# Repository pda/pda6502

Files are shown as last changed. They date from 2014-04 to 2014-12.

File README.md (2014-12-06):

pda6502
=======

pda6502 is a home-built computer powered by an 8-bit [6502][6502] CPU
([WDC 65C02][65C02]), varitions of which powered the venerable Commodore 64,
Apple II, Vic 20, Nintendo and lots more.

[74HC-series][7400] logic chips map the 64K address space to 32K RAM, 8K ROM, a
[6522 VIA I/O controller][6522], and room for expansion.

The first output device (beyond flashing LEDs) is a [128x32 pixel OLED][oled],
connected to one of the VIA 6522 parallel ports, with bit-banged serial comms.

It's currently exclusively running the 6502 assembly code which I've written in
the `src/` directory of this project. As of April 2014, it can bit-bang SPI on
the VIA parallel ports to drive the OLED display, rendering text using the old
Commodore 64 font data.

The code is assembled with [ca65][ca65], part of the [cc65][cc65] 6502
development package.

Notes
-----

ILI9340 SPI performance; filling 200x200 square.
baseline: 4.5 seconds.

Emulator
--------

I've also written [go6502][go6502], an emulator for this system.

go6502 features a stepping debugger with breakpoints on instruction type,
register values and memory location. This makes it far easier to get code
working correctly before writing it to an actual EEPROM.

Address layout
--------------

Considerations:

* 6502 has 16-bit address bus; can address 64K memory.
* Zero-page (0x0000..0x00FF) must be RAM, used as external registers.
* Stack (0x0100..0x00FF) must be RAM.
* PC (program counter) is initialized from 0xFFFC, so must be ROM.
* 6522 VIA (I/O) has 4-bit RS (register select), needs 16 bytes mapped.
* AT28C64 EEPROMs are 8kb. I have some.
* Nice to have:
  * Fancy bank-switching (e.g. ROMs overlaying RAM, C64-style).
  * Different mapping for read vs. write, e.g. read ROM, write RAM.

74HC521/74HC688 can route a specific page (256 bytes, upper 8 bits of address)
to a destination. See http://wilsonminesco.com/6502primer/addr_decoding.html

So using the highest three pins of the address bus, the memory space
can be divided down to 8K blocks.

A simple RAM+ROM+IO scheme:
Allows for future extensions e.g. upper 32K RAM, with ROMs and I/O overlaid.

* 0x0000..0x7FFF: 32K RAM, uninterrupted. Contains zero-page and stack.
* 0x8000..0xBFFF: (reserved)
* 0xC000..0xCFFF: 4K I/O (initially only 16 bytes used by 6522 VIA)
* 0xD000..0xDFFF: (reserved)
* 0xE000..0xFFFF: 8K ROM ("kernal" [sic])

Address table for upper 3 bits of address bus:

NOTE: A15 can directly control RAM's CE/OE.
      This means a 74HC138 decoder can run on A12..14
      (With A15 as the '138 active-high enable input)

Address bus 4 KB chunks:

```
     High   Dec  Dec
Seg  Bits    In  Out  Base    Function
------------------------------------------------
  0  0000             0x0000  RAM
  1  0001             0x1000  RAM
  2  0010             0x2000  RAM
  3  0011             0x3000  RAM
  4  0100             0x4000  RAM
  5  0101             0x5000  RAM
  6  0110             0x6000  RAM
  7  0111             0x7000  RAM
  8  1000   000    0  0x8000
  9  1001   100    4  0x9000  IO (VIA) (should be at 0xC000)
  A  1010   010    2  0xA000
  B  1011   110    6  0xB000  ROM (KERNAL) (should be at 0xE000)
  C  1100   001    1  0xC000
  D  1101   101    5  0xD000
  E  1110   011    3  0xE000
  F  1111   111    7  0xF000  ROM (KERNAL)
```

* 74HC138 (3-to-8 decoder)
    * G1 (active-high enable) driven by A15 (only active 0x8000 and above)
    * G2 (active-low enable) permanently LOW/enabled.
    * Inputs A, B, C driven by A12, A13, A14.
    * Output Y4 enables VIA.
    * Output Y6 & Y7 drive KERNAL ROM via AND gate.
* 74HC08 (Quad 2-input AND gates)
    * Input A1, B1 from 74HC138 Y6, Y7, output Y1 to KERNAL ROM CE/OE.
    * Input A2, B2 from phase2, A15, output Y2 to RAM CS/OE.
    * Three spare AND gates.
* 74HC00 (Quad 2-input NAND gates)
    * Input A1, B1 from A15 (as inverter), output Y1 to A2.
    * Input A2, B2 from Y1, phase2 clock, output Y2 to RAM CS/OE.
* VIA 6522
    * CS1 permanently HIGH/active.
    * CS2B to 74HC138 Y4 (LOW/active for `0b1110____`).
    * Data 0..7 to data bus D0..7.
    * Address 0..3 to address bus A0..3.
    * RWB to 6502 RWB.
    * PHI2 to system oscillator, same as 6502.
    * RESB to reset button, same as 6502.
* ROM AT28C64
    * CE and OE both active-low, tied together.
    * CE/OE to 74HC08 Y1, (LOW/active for `0b111_____`)
    * WE permanently HIGH/inactive.
    * I/O 0..7 to data bus D0..7.
    * Address 0..12 to address bus A0..12.
* RAM (32Kx8 CMOS SRAM; UM61256AK-12)
    * CE and OE both active-low, tied together.
    * CE/OE driven by A15+phase2 via 74HC00 (LOW/active for `0b0_______`)
    * WE (active low) to 6502 RWB.
    * Address 0..14 to address bus A0..14.

Zero Page
---------

The zero page (`0x0000..0x00FF`) is frequently used as "external registers".

Note that Some 6502 derivatives dedicate the first few bytes to hardware ports and
control registers, best avoid those? e.g. 6510 in C64 uses at least two.

[6502]: http://en.wikipedia.org/wiki/MOS_Technology_6502
[65C02]: http://en.wikipedia.org/wiki/WDC_65C02
[6522]: http://en.wikipedia.org/wiki/MOS_Technology_6522
[7400]: http://en.wikipedia.org/wiki/List_of_7400_series_integrated_circuits
[oled]: https://www.adafruit.com/products/661
[golang]: http://golang.org/
[go6502]: https://github.com/pda/go6502
[ca65]: http://cc65.github.io/cc65/doc/ca65.html
[cc65]: http://cc65.github.io/cc65/

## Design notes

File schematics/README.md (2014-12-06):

pda6502 schematics
==================

Schematics for pda6502 hardware builds.

Disclaimer: I have no idea what I'm doing.

First iteration is aiming towards a core board for the 6502, 6522, ROM, RAM and
oscillator.  It would connect the power, data bus, address bus, reset lines and
clock lines.  All other functionality (including memory-mapping logic) would be
external via headers.

A 2x10 header exposes the 6522 VIA ports A and B and their control lines.

Notes / TODO
------------

ERRORS:

* A,B,C inputs to 74HC138 reversed!
    * Moves VIA from $C000 to $9000.
    * Moves lower half of kernal ROM from $E000 to $B000.
* 47uF cap footprint too small.
* reset button footprint too small.
* Expansion font too light for silkscreen printing.

Micro B USB socket:
Dangerous Prototypes Eagle library.
Device: CONN-USB-MICRO-B
USB micro-b connector SMT 0.65 mm pitch, 1.45mm from center to PCB edge, Based on TE part number 1981568-1
http://www.mouser.com/ProductDetail/TE-Connectivity-AMP/1981568-1/?qs=zxTme0yW/baAfvOKTKC5hw==

Memory mapping logic
--------------------

* IN:  CPU A12
* IN:  CPU A13
* IN:  CPU A14
* IN:  CPU A15
* IN:  CPU PHI2
* IN:  CPU PHI1O
* IN:  CPU RWB
* OUT: RAM OE+CE
* OUT: ROM OE+CE
* OUT: VIA CS2B

Logic chips:

* 74HC00 (quad NAND) acting as inverter, NAND gate, and AND gate.
* 74HC138 (3-bit decoder) to split the upper-half of address space.

Propagation times:

* 74HC00 gates: typical 8 ns, max 23 ns.
* 74HC138: typical 15 ns, max 38 ns.

* RAM: invert (NAND) + NAND = typical 16 ns, max 46 ns.
* VIA: 74HC138 = typical 15 ns, max 38 ns.
* ROM: 74HC138 + (NAND + NAND) = typical 31 ns, max 84 ns.

* RAM speed: 12 ns
* ROM speed: 250 ns or 120 ns? 150 ns for Atmel AT28C256-15

Power characteristics
---------------------

Designing for maximum of 1A current should be plenty:

[vreg]: http://www.mouser.com/Search/ProductDetail.aspx?R=MC7805CDTRKGvirtualkey58410000virtualkey863-MC7805CDTRKG

```
65C02: 12 mA @ 8 MHz; 1.5 mA per MHz supply current (loaded)
65C22:  4 mA @ 8 MHz; 0.5 mA per MHz supply current (loaded)
28C64: 30 mA max.
SRAM: 200 mA max; 80 mA typical
      ==========
      246 mA max (chips)
      ==========
TFT:  100 mA
uSD:  100 mA (max during writes)
xprot: 60 mA
oled:  20 mA
      ==========
      526 mA
      ==========
```

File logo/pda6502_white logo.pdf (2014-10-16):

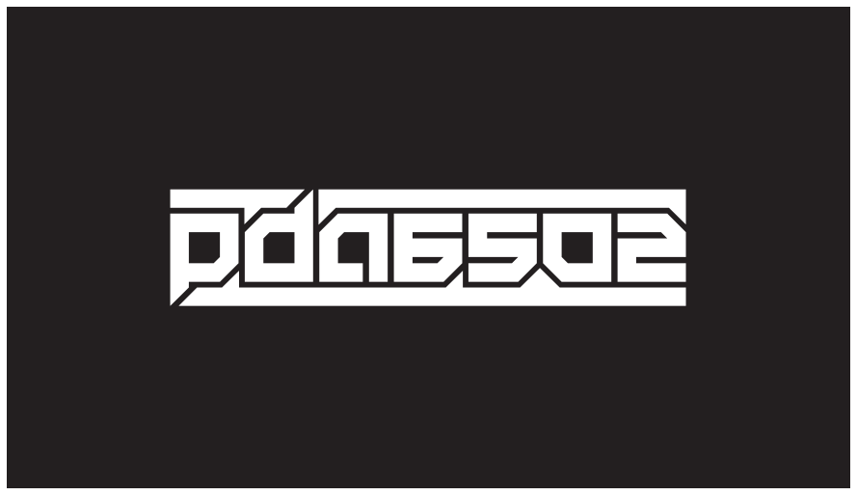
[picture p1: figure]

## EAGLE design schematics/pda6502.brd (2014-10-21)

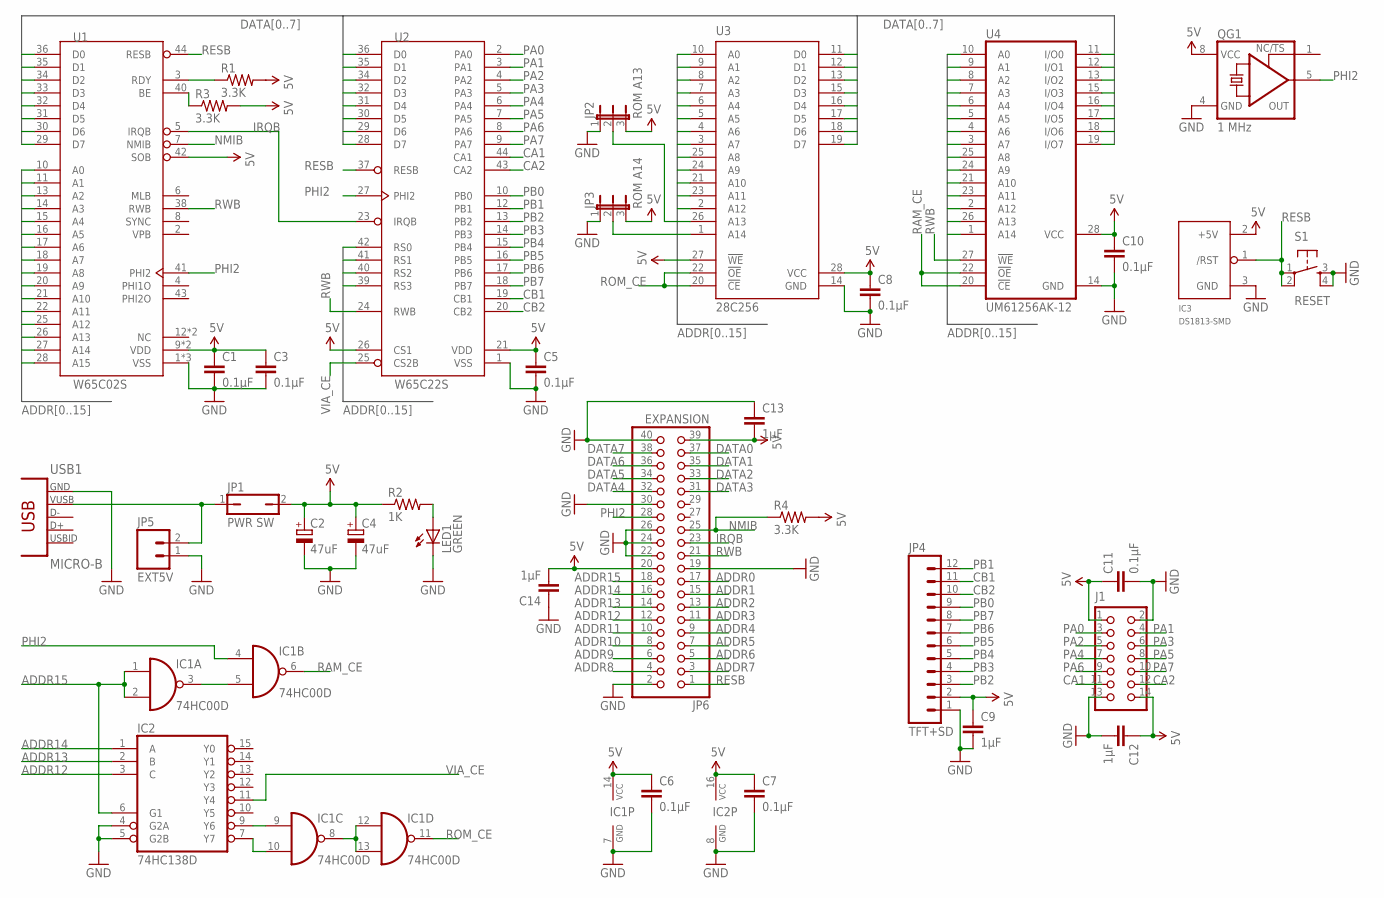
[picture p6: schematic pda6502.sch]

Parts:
C1, C3, C5, C6, C7, C8, C10, C11: 0.1μF; C0805
C2, C4: 47uF; CASE_B
C9, C12, C13, C14: 1μF; C0805
IC1: 74HC00D; SO14
IC2: 74HC138D; SO16
IC3: DS1813-SMD; SOT-23
J1: CON_HEADER_2X07-PTH; M2X7
JP1: PWR SW; JMP-1X2
JP2: ROM A13; JP2
JP3: ROM A14; JP2
JP4: TFT+SD; 1X12_NO_SILK_KIT
JP5: EXT5V; 1X02
JP6: EXPANSION; 2X20
LED1: GREEN; LED-805
QG1: 1 MHz; DIL08S
R1, R3, R4: 3.3K; R0805
R2: 1K; R0805
S1: RESET; TACTILE-SWITCH-SMD
U1: W65C02S; PLCC44-SOCKET
U2: W65C22S; PLCC44-SOCKET
U3: 28C256; ZIF28-6-WIDE
U4: UM61256AK-12; DIL28-3
USB1: MICRO-B; CONN_USB_MICRO-B

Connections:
5V: C1.1, C2.+, C3.1, C4.+, C5.1, C6.1, C7.1, C8.1, C9.1, C10.1, C11.1, C12.1, C13.2, C14.2, IC1.14 (VCC), IC2.16 (VCC), IC3.2 (+5V), J1.1, J1.14, JP1.2, JP2.3, JP3.3, JP4.2, JP6.20, JP6.39, QG1.8 (VCC), R1.2, R2.1, R3.2, R4.2, U1.9 (VDD), U1.37 (VDD), U1.42 (SOB), U2.21 (VDD), U2.26 (CS1), U3.27 (!WE), U3.28 (VCC), U4.28 (VCC)
ADDR0: JP6.17, U1.10 (A0), U2.42 (RS0), U3.10 (A0), U4.10 (A0)
ADDR1: JP6.15, U1.11 (A1), U2.41 (RS1), U3.9 (A1), U4.9 (A1)
ADDR2: JP6.13, U1.13 (A2), U2.40 (RS2), U3.8 (A2), U4.8 (A2)
ADDR3: JP6.11, U1.14 (A3), U2.39 (RS3), U3.7 (A3), U4.7 (A3)
ADDR4: JP6.9, U1.15 (A4), U3.6 (A4), U4.6 (A4)
ADDR5: JP6.7, U1.16 (A5), U3.5 (A5), U4.5 (A5)
ADDR6: JP6.5, U1.17 (A6), U3.4 (A6), U4.4 (A6)
ADDR7: JP6.3, U1.18 (A7), U3.3 (A7), U4.3 (A7)
ADDR8: JP6.4, U1.19 (A8), U3.25 (A8), U4.25 (A8)
ADDR9: JP6.6, U1.20 (A9), U3.24 (A9), U4.24 (A9)
ADDR10: JP6.8, U1.21 (A10), U3.21 (A10), U4.21 (A10)
ADDR11: JP6.10, U1.22 (A11), U3.23 (A11), U4.23 (A11)
ADDR12: IC2.3 (C), JP6.12, U1.25 (A12), U3.2 (A12), U4.2 (A12)
ADDR13: IC2.2 (B), JP6.14, U1.26 (A13), U4.26 (A13)
ADDR14: IC2.1 (A), JP6.16, U1.27 (A14), U4.1 (A14)
ADDR15: IC1.1 (I0), IC1.2 (I1), IC2.6 (G1), JP6.18, U1.28 (A15)
CA1: J1.11, U2.44 (CA1)
CA2: J1.12, U2.43 (CA2)
CB1: JP4.11, U2.19 (CB1)
CB2: JP4.10, U2.20 (CB2)
DATA0: JP6.37, U1.36 (D0), U2.36 (D0), U3.11 (D0), U4.11 (I/O0)
DATA1: JP6.35, U1.35 (D1), U2.35 (D1), U3.12 (D1), U4.12 (I/O1)
DATA2: JP6.33, U1.34 (D2), U2.34 (D2), U3.13 (D2), U4.13 (I/O2)
DATA3: JP6.31, U1.33 (D3), U2.32 (D3), U3.15 (D3), U4.15 (I/O3)
DATA4: JP6.32, U1.32 (D4), U2.31 (D4), U3.16 (D4), U4.16 (I/O4)
DATA5: JP6.34, U1.31 (D5), U2.30 (D5), U3.17 (D5), U4.17 (I/O5)
DATA6: JP6.36, U1.30 (D6), U2.29 (D6), U3.18 (D6), U4.18 (I/O6)
DATA7: JP6.38, U1.29 (D7), U2.28 (D7), U3.19 (D7), U4.19 (I/O7)
GND: C1.2, C2.-, C3.2, C4.-, C5.2, C6.2, C7.2, C8.2, C9.2, C10.2, C11.2, C12.2, C13.1, C14.1, IC1.7 (GND), IC2.4 (G2A), IC2.5 (G2B), IC2.8 (GND), IC3.3 (GND), J1.2, J1.13, JP2.1, JP3.1, JP4.1, JP5.1, JP6.2, JP6.19, JP6.22, JP6.24, JP6.26, JP6.30, JP6.40, LED1.C, QG1.4 (GND), S1.3, S1.4, U1.1 (VSS), U1.23 (VSS), U1.24 (VSS), U2.1 (VSS), U3.14 (GND), U4.14 (GND), USB1.P5 (GND)
IRQB: JP6.23, U1.5 (IRQB), U2.23 (IRQB)
unnamed: LED1.A, R2.2
unnamed: IC1.10 (I1), IC2.7 (Y7)
unnamed: IC1.9 (I0), IC2.9 (Y6)
unnamed: JP1.1, JP5.2, USB1.P1 (VUSB)
unnamed: IC1.8 (O), IC1.12 (I0), IC1.13 (I1)
unnamed: JP3.2, U3.1 (A14)
unnamed: IC1.3 (O), IC1.5 (I1)
unnamed: R3.1, U1.40 (BE)
unnamed: R1.1, U1.3 (RDY)
unnamed: JP2.2, U3.26 (A13)
NMIB: JP6.25, R4.1, U1.7 (NMIB)
PA0: J1.3, U2.2 (PA0)
PA1: J1.4, U2.3 (PA1)
PA2: J1.5, U2.4 (PA2)
PA3: J1.6, U2.5 (PA3)
PA4: J1.7, U2.6 (PA4)
PA5: J1.8, U2.7 (PA5)
PA6: J1.9, U2.8 (PA6)
PA7: J1.10, U2.9 (PA7)
PB0: JP4.9, U2.10 (PB0)
PB1: JP4.12, U2.12 (PB1)
PB2: JP4.3, U2.13 (PB2)
PB3: JP4.4, U2.14 (PB3)
PB4: JP4.5, U2.15 (PB4)
PB5: JP4.6, U2.16 (PB5)
PB6: JP4.7, U2.17 (PB6)
PB7: JP4.8, U2.18 (PB7)
PHI2: IC1.4 (I0), JP6.28, QG1.5 (OUT), U1.41 (PHI2), U2.27 (PHI2)
RAM_CE: IC1.6 (O), U4.20 (!CE), U4.22 (!OE)
RESB: IC3.1 (/RST), JP6.1, S1.1, S1.2, U1.44 (RESB), U2.37 (RESB)
ROM_CE: IC1.11 (O), U3.20 (!CE), U3.22 (!OE)
RWB: JP6.21, U1.38 (RWB), U2.24 (RWB), U4.27 (!WE)
VIA_CE: IC2.11 (Y4), U2.25 (CS2B)

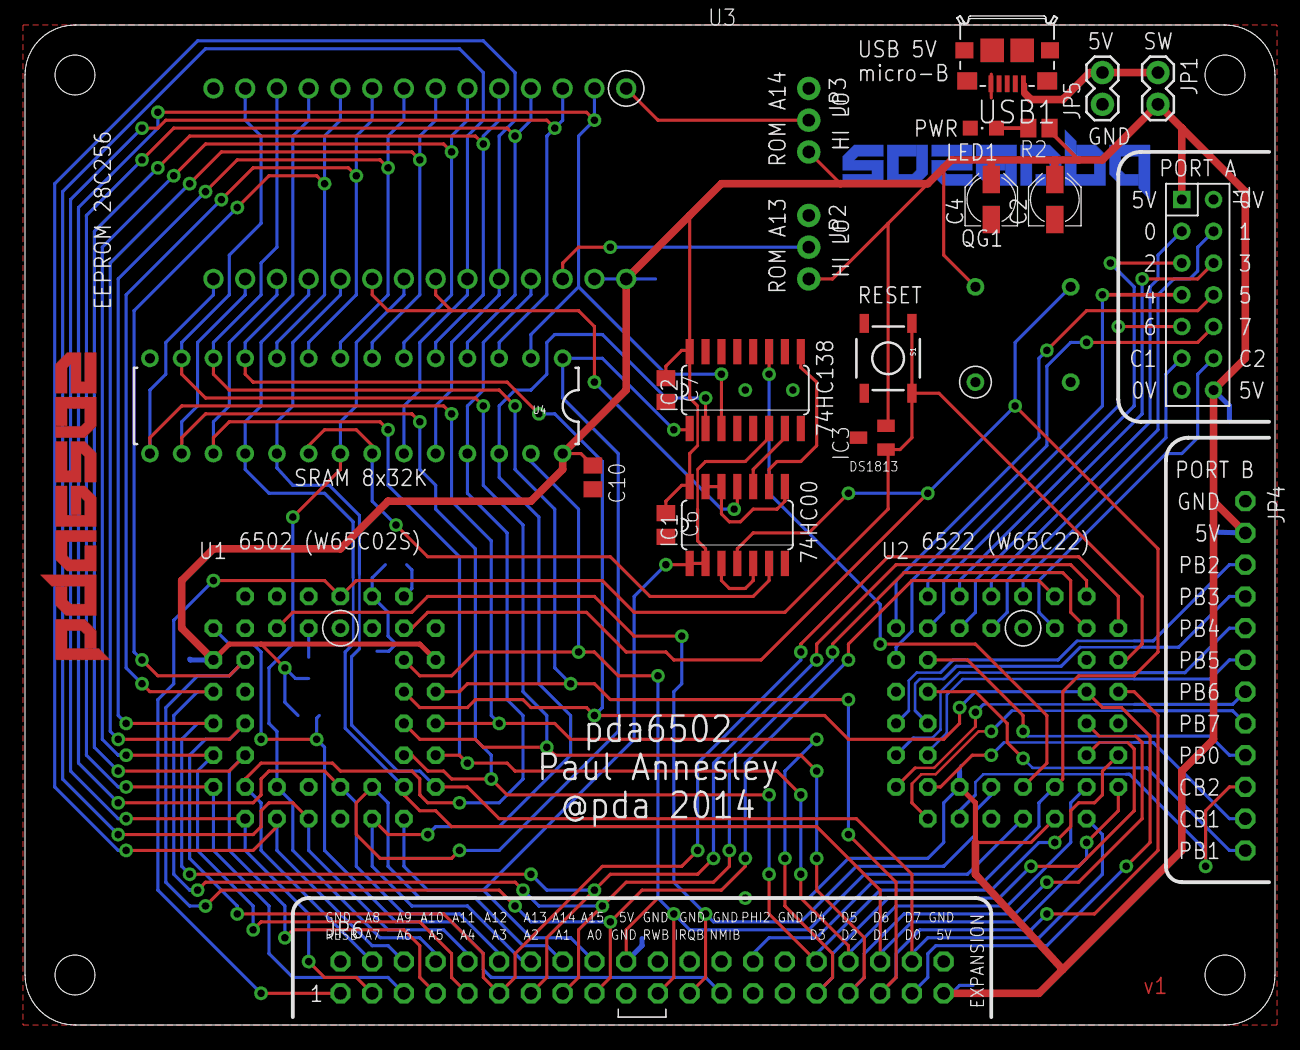
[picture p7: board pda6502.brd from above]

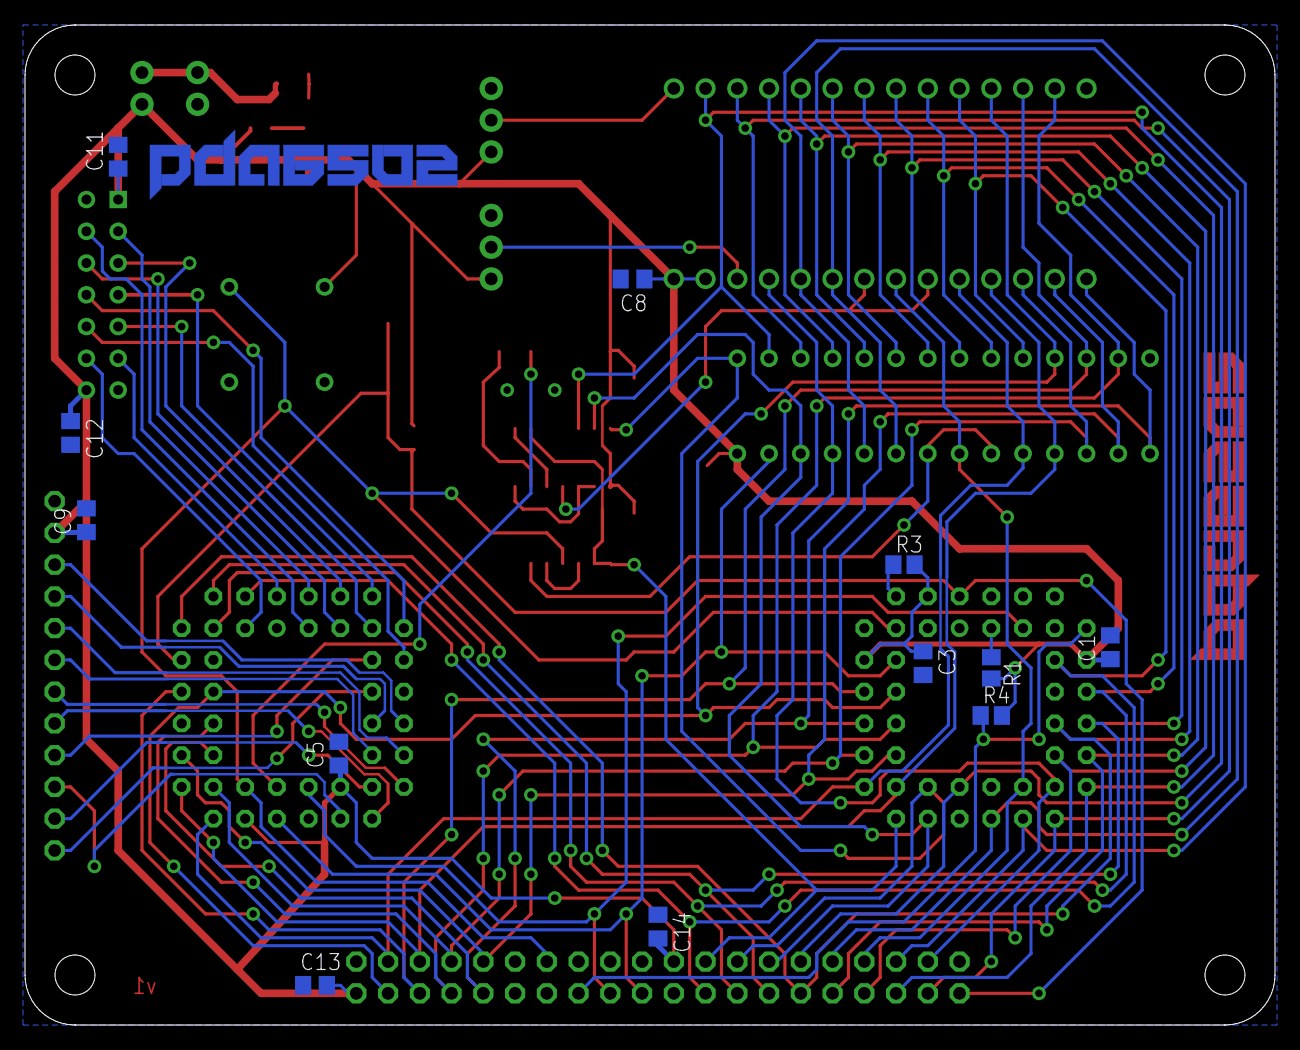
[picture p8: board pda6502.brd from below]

Board: 2 copper layers, 100.0 x 80.0 mm, 40 parts (13 on the bottom side), 64 nets.

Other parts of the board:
U$1: DP10080_V1
U$2: ADA-TFT-240X230-22INCH
U$3, U$4: PDA6502-LOGO

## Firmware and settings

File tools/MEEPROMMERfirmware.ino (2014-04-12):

/**
 * ** project Arduino EEPROM programmer **
 * 
 * This sketch can be used to read and write data to a
 * AT28C64 or AT28C256 parallel EEPROM
 *
 * $Author: mario, edited by Zack $
 * $Date: 2013/05/05 11:01:54 $
 * $Revision: 1.3 $
 *
 * This software is freeware and can be modified, reused or thrown away without any restrictions.
 *
 * Use this code at your own risk. I'm not responsible for any bad effect or damages caused by this software!!!
 *
 **/

#define VERSIONSTRING "MEEPROMMER $Revision: 1.3 $ $Date: 12/18/2013 15:56:00 $, CMD:R,r,w,W,V, u"

// shiftOut part
#define PORTC_DS      0
#define PORTC_LATCH   1
#define PORTC_CLOCK   2

// eeprom IO lines:D0-D7 = pins2-9

// IO lines for the eeprom control
#define PORTC_CE   3
#define PORTC_OE   4
#define PORTC_WE   5

//a buffer for bytes to burn
#define BUFFERSIZE 1024 
byte buffer[BUFFERSIZE];
//command buffer for parsing commands
#define COMMANDSIZE 16
char cmdbuf[COMMANDSIZE];

unsigned int startAddress,endAddress;
unsigned int lineLength,dataLength;

//define COMMANDS
#define NOCOMMAND    0
#define VERSION      1

#define READ_HEX    10
#define READ_BIN    11

#define WRITE_PAGE  20
#define WRITE_BIN   21

#define UNLOCK      30

/*****************************************************************
 *
 *  CONTROL and DATA functions
 *
 ****************************************************************/

void data_bus_input(){
  DDRD &= 0b00000011;
  DDRB &= 0b11111100;
}

void data_bus_output(){
  DDRD |= 0b11111100;
  DDRB |= 0b00000011;
}

byte read_data_bus(){
  return ((PINB<<6)|(PIND>>2));
}

void write_data_bus(byte data){
  PORTB &= 0b11111100;  
  PORTB |= (data>>6);
  PORTD &= 0b00000011;
  PORTD |= (data<<2);
}

//shift out the given address to the 74hc595 registers
void set_address_bus(unsigned int address){
  bitClear(PORTC,PORTC_LATCH);		//disable latch line
  fastShiftOut(highByte(address));	//shift out highbyte
  fastShiftOut(lowByte(address));	//shift out lowbyte
  bitSet(PORTC,PORTC_LATCH);		//enable latch and set address
}

void fastShiftOut(byte data){
  for(int i=7; i>=0; i--){//shift MSB first
    //clear data pin after shift to prevent bleed through
    bitClear(PORTC,PORTC_DS);
    bitClear(PORTC,PORTC_CLOCK);
    if(bitRead(data,i))bitSet(PORTC,PORTC_DS);
    //register shifts bits on rising clock
    bitSet(PORTC,PORTC_CLOCK);
  }
  bitClear(PORTC,PORTC_CLOCK);
}

byte read_byte(unsigned int address){
  data_bus_input();			//set databus for reading
  bitClear(PORTC,PORTC_CE);	//enable chip select
  bitSet(PORTC,PORTC_WE);	//disable write
  set_address_bus(address);	//set address bus
  bitClear(PORTC,PORTC_OE);	//enable output
  //delay 312.5ns @ 16MHz
  __asm__("nop\n\t""nop\n\t""nop\n\t""nop\n\t""nop\n\t");
  byte data = read_data_bus();
  bitSet(PORTC,PORTC_OE);	//disable output
  bitSet(PORTC,PORTC_CE);	//enable chip select
  return data;
}

void fast_write(unsigned int address, byte data){
  bitSet(PORTC,PORTC_OE);	//first disable output
  bitSet(PORTC,PORTC_WE);	//disable write
  set_address_bus(address);	//set address bus
  data_bus_output();		//set databus to output
  write_data_bus(data);		//set data bus
  bitClear(PORTC,PORTC_CE);	//enable chip select
  bitClear(PORTC,PORTC_WE);	//enable write
  __asm__("nop\n\t""nop\n\t");  //delay 125ns @ 16MHz
  bitSet(PORTC,PORTC_WE);	//disable write
  data_bus_input();
  bitClear(PORTC,PORTC_OE);
  //delay 312.5ns @ 16MHz
  __asm__("nop\n\t""nop\n\t""nop\n\t""nop\n\t""nop\n\t");
  while(data != read_data_bus()); //poll data
  bitSet(PORTC,PORTC_OE);
  bitSet(PORTC,PORTC_CE);
}

void write_block_page(unsigned int address, byte* buffer, int len, int page){
  address &= ~(page-1);	//address must not break page boundaries
  bitSet(PORTC,PORTC_WE);	//disable write
  bitClear(PORTC,PORTC_CE);	//enable chip
  for(int n=0; n<len/page; n++){
    bitSet(PORTC,PORTC_OE);
    data_bus_output();		//set databus to output
    for(unsigned int i=n*page; i<(n+1)*page; i++){
      bitSet(PORTC,PORTC_WE);		//disable write
      set_address_bus(address+i);	//set address bus
      write_data_bus(buffer[i]);	//set data bus
      bitClear(PORTC,PORTC_WE);		//enable write
      //100ns+ tWP delay caused by for looping
    }
    bitSet(PORTC,PORTC_WE);		//write must be high for tBLC(100us)
    data_bus_input();
    bitClear(PORTC,PORTC_OE);	//enable output
    //delay 312.5ns @ 16MHz
    __asm__("nop\n\t""nop\n\t""nop\n\t""nop\n\t""nop\n\t");
    while(buffer[(n+1)*page-1] != read_data_bus()); //poll data
  }
  bitSet(PORTC,PORTC_CE);
}

/************************************************
 *
 * COMMAND and PARSING functions
 *
 *************************************************/

void readCommand(){
  int idx = 0;
  do {//read 'til linebreak or buffer is full
    if(Serial.available())cmdbuf[idx++] = Serial.read();
  } while (cmdbuf[idx-1] != '\n' && idx < COMMANDSIZE);
  for(;idx<COMMANDSIZE;idx++)cmdbuf[idx] = 0;//clear the rest of command buffer 
}

byte parseCommand(){
  //command format:C AAAA DDDD LL
  startAddress=hexWord(cmdbuf+2);	//A
  dataLength=hexWord(cmdbuf+7);	//D
  lineLength=hexByte(cmdbuf+12);	//L
  switch(cmdbuf[0]){
  case 'R':
    return(READ_HEX);
  case 'r':
    return(READ_BIN);
  case 'W':
    return(WRITE_PAGE);
  case 'w': 
    return(WRITE_BIN);
  case 'V':
    return(VERSION);
  case 'u':
    return(UNLOCK);
  default:
    return(NOCOMMAND);
  }
}

byte hexDigit(char c){ //ascii char to value
  if(c >= '0' && c <= '9')return c - '0';
  if(c >= 'a' && c <= 'f')return c - 'a' + 10;
  if(c >= 'A' && c <= 'F')return c - 'A' + 10;
  return 0;// getting here is bad: it means the character was invalid
}

byte hexByte(char* a){ //ascii byte to value
  return ((hexDigit(a[0])<<4) | hexDigit(a[1]));
}

//ascii word to value
unsigned int hexWord(char* data){
  return ((hexDigit(data[0])<<12)|
    (hexDigit(data[1])<<8)|
    (hexDigit(data[2])<<4)|
    (hexDigit(data[3]))); 
}


/************************************************
 *
 * INPUT / OUTPUT Functions
 *
 *************************************************/

void read_block(unsigned int from, unsigned int to, int linelength){
  int outcount = 0;
  //loop from "from address" to "to address" (included)
  for(unsigned int address = from; address <= to; address++){
    if(outcount == 0){
      //print out the address at the beginning of the line
      Serial.println();
      Serial.print("0x");
      printAddress(address);
      Serial.print(" : ");
    }
    //print data, separated by a space
    printByte(read_byte(address));
    Serial.print(" ");
    outcount = (++outcount % linelength);
  }
  Serial.println();
}

void read_binblock(unsigned int from, unsigned int to){
  for(unsigned int address = from; address <= to; address++){
    Serial.write(read_byte(address));
  }
  Serial.print('\0');//success return code
}  

void write_block(unsigned int address, byte* buffer, int len){
  for(unsigned int i = 0; i < len; i++){
    fast_write(address+i,buffer[i]);
  }   
}

void printAddress(unsigned int address){
  if(!(address & 0xfff0)) Serial.print("0");
  if(!(address & 0xff00)) Serial.print("0");
  if(!(address & 0xf000)) Serial.print("0");
  Serial.print(address, HEX);
}

void printByte(byte data){
  if(!(data & 0xf0)) Serial.print("0");
  Serial.print(data, HEX);  
}


/************************************************
 *
 * MAIN
 *
 *************************************************/
void setup(){
  DDRC = 0b00111111;	//set EEPROM & shiftOut Pins as output
  PORTC = 0b00111000;	//set EEPROM Pins high
  //Serial.begin(57600);	//set speed of serial connection
  Serial.begin(115200);
}

void loop(){
  int bytes = 0;
  readCommand();
  switch(parseCommand()){
  case READ_HEX:
    if(lineLength==0) lineLength=32; //default
    endAddress = startAddress + dataLength -1;
    read_block(startAddress,endAddress,lineLength);
    Serial.println('%');//success return code
    break;
  case READ_BIN:
    endAddress = startAddress + dataLength -1;
    read_binblock(startAddress,endAddress);
    break;
  case WRITE_PAGE:
    if(dataLength > 1024) dataLength = 1024;
    while(bytes < dataLength)if(Serial.available())buffer[bytes++] = Serial.read();
    if(lineLength==0) lineLength=32; //page size
    write_block_page(startAddress,buffer,dataLength,lineLength);
    Serial.println('%');
    break;
  case WRITE_BIN:
    if(dataLength > 1024) dataLength = 1024; //1024 is max
    while(bytes < dataLength)if(Serial.available())buffer[bytes++] = Serial.read();
    write_block(startAddress,buffer,dataLength);
    Serial.println('%');
    break;
  case VERSION:
    Serial.println(VERSIONSTRING);
    break;
  case UNLOCK:
    fast_write(0x5555,0xAA);
    fast_write(0x2AAA,0x55);
    fast_write(0x5555,0x80);
    fast_write(0x5555,0xAA);
    fast_write(0x2AAA,0x55);
    fast_write(0x5555,0x20);
    Serial.print('%');//success return code
    break;
  }
}

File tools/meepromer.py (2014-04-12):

#!/usr/bin/env python3

#Meeprommer commandline interface
#By Zack Nelson
#Project Home:
#https://github.com/mkeller0815/MEEPROMMER
#http://www.ichbinzustaendig.de/dev/meeprommer-en

# Some tweaks by @pda

import serial, sys, argparse

# Parse command line arguments
parser = argparse.ArgumentParser(
        description='Meepromer Command Line Interface',
        epilog='Read source for further information')

task = parser.add_mutually_exclusive_group()
task.add_argument('-V', '--version', dest="cmd", action="store_const",
        const="version", help='Request and display device version')
task.add_argument('-w', '--write', dest="cmd", action="store_const",
        const="write", help='Write to EEPROM')
task.add_argument('-W', '--write_paged', dest="cmd", action="store_const",
        const="write_paged", help='Fast paged write to EEPROM')
task.add_argument('-r', '--read', dest="cmd", action="store_const",
        const="read", help='Read from EEPROM as ascii')
task.add_argument('-d', '--dump', dest="cmd", action="store_const",
        const="dump", help='Dump EEPROM to binary file')
task.add_argument('-v', '--verify', dest="cmd", action="store_const",
        const="verify", help='Compare EEPROM with file')
task.add_argument('-u', '--unlock', dest="cmd", action="store_const",
        const="unlock", help='Unlock EEPROM')
task.add_argument('-l', '--list', dest="cmd", action="store_const",
        const="list", help='List serial ports')

parser.add_argument('-a', '--address', action='store', default='0',
        help='Starting eeprom address (as hex), default 0')
parser.add_argument('-o', '--offset', action='store', default='0',
        help='Input file offset (as hex), default 0')
parser.add_argument('-b', '--bytes', action='store', default='8',
        type=int, help='Number of kBytes to r/w, default 8')
parser.add_argument('-p', '--page_size', action='store', default='32',
        type=int, help='Number of bytes per EEPROM page e.g.:'+
            'CAT28C*=32, AT28C*=64, X28C*=64, default 32')
parser.add_argument('-f', '--file', action='store',
        help='Name of data file')
parser.add_argument('-c', '--com', action='store', 
        default='COM5', help='Com port address')
parser.add_argument('-s', '--speed', action='store', 
        type=int, default='115200', help='Com port baud, default 115200')

def list_ports():
    from serial.tools import list_ports
    for x in list_ports.comports():
        print(x[0], x[1])

def dump_file():
    ser.flushInput()
    ser.write(bytes("r "+format(args.address,'04x')+" "+
        format(args.address+args.bytes*1024,'04x')+
        " 10\n", 'ascii'))
    eeprom = ser.read(args.bytes*1024)
    if(ser.read(1) != b'\0'):
        print("Error: no Ack")
        sys.exit(1)
    try:
        fo = open(args.file,'wb+')
    except OSError:
        print("Error: File cannot be opened, verify it is not in use")
        sys.exit(1)
    fo.write(eeprom)
    fo.close()

def verify():
    print("Verifying...")
    ser.flushInput()
    ser.write(bytes("r "+format(args.address,'04x')+" "+
        format(args.bytes*1024,'04x')+" 10\n", 'ascii'))
    try:
        fi = open(args.file,'rb')
    except FileNotFoundError:
        print("Error: ",args.file," not found, please select a valid file")
        sys.exit(1)
    except TypeError:
        print("Error: No file specified")
        sys.exit(1)
        
    fi.seek(args.offset)
    file = fi.read(args.bytes*1024)
    eeprom = ser.read(args.bytes*1024)
    if ser.read(1) != b'\0':
        print("Error: no EOF received")
        
    if file != eeprom:
        print("Not equal")
        n = 0
        for i in range(args.bytes*1024):
            if file[i] != eeprom[i]:
                n+=1
        print(n,"differences found")
        sys.exit(1)
    else:
        print("Ok")

def read_eeprom():
    ser.flushInput()
    ser.write(bytes("R "+format(args.address,'04x')+" "+
        format(args.address+args.bytes*1024,'04x')+
        " 10\n", 'ascii'))
    ser.readline()#remove blank starting line
    for i in range(round(args.bytes*1024/16)):
        print(ser.readline().decode('ascii').rstrip())

def write_eeprom(paged):
    import time
    
    fi = open(args.file,'rb')
    fi.seek(args.offset)
    now = time.time() #start our stopwatch
    for i in range(args.bytes): #write n blocks of 1024 bytes
        output = fi.read(1024)
        print("Writing from",format(args.address+i*1024,'04x'),
              "to",format(args.address+i*1024+1023,'04x'))
        if paged:
            ser.write(bytes("W "+format(args.address+i*1024,'04x')+
                " 0400 "+format(args.page_size,'02x')+"\n", 'ascii'))
        else:
            ser.write(bytes("w "+format(args.address+i*1024,'04x')+
                " 0400 00\n", 'ascii'))

        ser.flushInput()
        ser.write(output)
        if(ser.read(1) != b'%'):
            print("Error: no Ack")
            sys.exit(1)
    print("Wrote",args.bytes*1024,"bytes in","%.2f"%(time.time()-now),"seconds")
    
def unlock():
    print("Unlocking...")
    ser.flushInput()
    ser.write(bytes("u 0000 0000 00\n", 'ascii'))
    if ser.read(1) != b'%':
        print("Error: no ack")
        sys.exit(1)

def version():
    ser.write(b'V\n')
    print(ser.readline().decode('ascii').rstrip())

args = parser.parse_args()
#convert our hex strings to ints
args.address = int(args.address,16)
args.offset = int(args.offset,16)

class DebugSerial(serial.Serial):
    def write(self, data):
        #print("write: %s" % (data,))
        super().write(data)

SERIAL_TIMEOUT = 20 #seconds
try:
    ser = DebugSerial(args.com, args.speed, timeout=SERIAL_TIMEOUT)
except serial.serialutil.SerialException:
    print("Error: Serial port is not valid, please select a valid port")
    sys.exit(1)

# It seems necessary to wait >= ~1.8 seconds for the device to respond.
import time
time.sleep(2)

if args.cmd == 'version':
    version()
elif args.cmd == 'write':
    write_eeprom(False)
elif args.cmd == 'write_paged':
    write_eeprom(True)
elif args.cmd == 'read':
    read_eeprom()
elif args.cmd == 'dump':
    dump_file()
elif args.cmd == 'verify':
    verify()
elif args.cmd == 'unlock':
    unlock();
elif args.cmd == 'list':
    list_ports()
    
ser.close()
sys.exit(0)

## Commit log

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2014-04-19 kernal.s attempts to draw bitmap to SSD1306 OLED.
    Currently appears to work correctly on emulator.
    Should be changed from VIA port A to B to maybe work on hardware.
2014-05-01 AsciiToPetscii corrected; SBC/BCS/BCC was wrong.
    > If you’re not used to 65x processors (and even for many programmers who
    > are), you may tend to write an ADC instruction without first writing a
    > CLC, or an SBC without first an SEC.
    -- WDC programmer manual
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2014-08-09 pda6502.sch schematic; WIP.
    Partial TODO list:
    * fix 65C22 symbol; VSS/VDD, ...
    * fix SRAM symbol / pinout
    * check EEPROM symbol / pinout
    * decoupling capacitors
    * crystal oscillator
    * power headers
    * glue logic headers
    * 24-pin bus header
    * CPU headers
    * IO headers
    * reset button / pull-up.
    * power-on-reset circuit?
    [pda6502.sch]
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2014-08-11 schematics: 2x10 pin header for VIA port A and B.
    [pda6502.sch]
2014-08-11 schematics: 2x20 header for address + data bus.
    Ground connections match those on a parallel ATA cable. Thus a
    40-connector 80-conductor (UDMA) cable can be used to interleave ground
    wires between signal wires.
    ADDRESS[0..15] here maps directly to DATA[0..15] in PATA.
    [pda6502.sch]
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2014-08-11 schematics: RWB connected 6502, 6522, RAM. Split named net.
    [pda6502.sch]
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2014-08-11 schematics: OE and CE tied together, for ROM and RAM.
    [pda6502.sch]
2014-08-11 schematics: decoupling caps for all ICs; 0.1uF 0805 SMD.
    [pda6502.sch]
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2014-08-11 schematics: reset circuit (DS1813); no button yet.
    [pda6502.sch]
2014-08-11 schematics: crystal oscillator; half can.
    [pda6502.sch]
2014-08-11 schematics: reset circuit has button.
    [pda6502.sch]
2014-08-11 schematics: VIA CS1 tied high (active). See active-low CS2B.
    [pda6502.sch]
2014-08-11 schematics: PHI2 net into 6502 fixed; was not connected.
    [pda6502.sch]
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2014-08-11 schematics: DIP28-SKINNY (bad) replaced by DIL28-3.
    The former was actually a wide package, despite name.
    The latter is taken from SparkFun's library.
2014-08-11 schematics: RAM package updated to fixed DIL28-3.
    [pda6502.sch]
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2014-08-11 schematics: W65C02 naming corrections / tweaks.
    [pda6502.sch]
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2014-08-20 schematics: jumper together connected sides of reset button.
    [pda6502.sch]
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2014-08-21 schematics: 7805 regulator package swapped to TO252 (DPAK).
    [pda6502.sch]
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2014-08-21 schematics: deleted voltage regulator; assume 5VDC input.
    A switching mode 5V DC wall adapter should be fine.
    [pda6502.sch]
2014-08-22 schematics: micro USB for power, with 2 x 47uF caps, and LED.
    [pda6502.sch]
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2014-08-23 schematics: 28C256 ROM with HI/LO jumpers on A13, A14.
    [pda6502.sch]
2014-08-23 schematics: rearranged; memory mapping bottom right, PSU bottom left.
    [pda6502.sch]
2014-08-24 schematics: 6502 IRQ to 6522, unused active-low inputs to VCC.
    [pda6502.sch]
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2014-08-24 schematics: removed 2x10 VIA header (PA + PB).
    [pda6502.sch]
2014-08-24 schematics: VIA exposes two 2x7 headers; port A and port B.
    [pda6502.sch]
2014-08-24 schematics: layout tweaks and errors corrected in schematic.
    [pda6502.sch]
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2014-08-24 schematics: TFT+SD header on PORTB for shift-register.
    SR used as PWM to control backlight.
    [pda6502.sch]
2014-08-28 schematics: PORTB hdr changed, 40-pin hdr is back.
    [pda6502.sch]
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2014-08-28 board: routed USB power, jumper, header, caps, LED etc.
    [pda6502.brd]
2014-08-28 board: routed decoupling caps to power pins, etc.
    [pda6502.brd]
2014-08-28 board: routed a few adjacent 5V pins to each other.
    [pda6502.brd]
2014-08-28 board: routed OE and CE to each other on RAM and ROM.
    [pda6502.brd]
2014-08-31 board: alternate grid set to 0.005 as per SparkFun article.
    [pda6502.brd]
2014-08-31 board: ROM and RAM buses routed to each other. Widths changes.
    Trace widths changed, possibly across entire board. Needs review later.
    [pda6502.brd]
2014-08-31 board: layout tweaks; oscillators and memory mapping.
    [pda6502.brd]
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2014-08-31 schematics: ERC fixes; expansion header has decoupling cap.
    (Does the cap even make sense there? The more the merrier...)
    [pda6502.sch]
2014-09-01 board: routing WIP.
    I can't actually remember what changed in this commit. Perhaps it was
    just forward-annotation from schematic fixes in previous commit.
    [pda6502.brd]
2014-09-01 board: routing WIP; thick power traces, reaching more devices.
    [pda6502.brd]
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2014-09-02 board: USB socket closer to edge; routing adjusted.
    [pda6502.brd]
2014-09-02 board: routed 40-pin expansion header ADDRESS pins to 6502.
    [pda6502.brd]
2014-09-03 board: routing WIP: 5V edge lines shifted in.
    [pda6502.brd]
2014-09-03 board: re-routed expansion port address lines to 6502.
    [pda6502.brd]
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2014-09-06 board: PORTB bumped north; fine trace width normalized, tweaks.
    [pda6502.brd]
2014-09-06 schematic, board: added 0.1 uF cap on 5V expansion pin 20.
    [pda6502.brd, pda6502.sch]
2014-09-06 board: routed ADDR[0..7, 12] down left side of board.
    [pda6502.brd]
2014-09-06 board: trace spacing less tight; 0.025 grid for most routing.
    [pda6502.brd]
2014-09-06 board: 6502 moved 50 mils left; more space in center.
    [pda6502.brd]
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2014-09-10 board: routing WIP; 74xx chips on bottom layer.
    [pda6502.brd]
2014-09-10 board: SMD logic chips routed; top layer of board.
    [pda6502.brd]
2014-09-10 board: traces around RAM/ROM have width 0.01 mil.
    [pda6502.brd]
2014-09-10 board: 6502 bumped 50 mils right; left-side traces straightened.
    [pda6502.brd]
2014-09-13 board: 6502 bumped further right; opens gap for ground pour.
    [pda6502.brd]
2014-09-13 board: clearance to right of 6502 for ground pour.
    [pda6502.brd]
2014-09-13 board: 6 airwires; likely all GND plane issues.
    [pda6502.brd]
2014-09-13 board: tweaks to maximize bottom GND plane; 4 airwires.
    [pda6502.brd]
2014-09-13 board: vias under RAM adjusted; 3 airwires remaining.
    [pda6502.brd]
2014-09-13 board: expanded GND pour around 74HC chips; 1 airwire remaining.
    [pda6502.brd]
2014-09-13 board: main power re-routed; more ground plane. 0 airwires!
    [pda6502.brd]
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2014-09-13 board: USB connector bumped down for edge alignment.
    [pda6502.brd]
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2014-09-13 board: tidied under 6502; R1 and C3 tigher layout.
    [pda6502.brd]
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2014-09-14 board: tweaks for increased ground-fill on top layer.
    [pda6502.brd]
2014-09-14 board: alternate grid of 0.025 inch, not 0.005.
    This makes the alternate grid just half, not a fifth, of the primary.
    When necessary, it can be temporarily changed to 0.005.
    This has been the case for most of the work leading up to this commit.
    [pda6502.brd]
2014-09-18 board: layout tweaks; clock, reset, power LED etc.
    [pda6502.brd]
2014-09-18 schematics, board: NMIB to expansion port, with pull-up resistor.
    [pda6502.brd, pda6502.sch]
2014-09-18 board: power caps have greater clearance from edge.
    [pda6502.brd]
2014-09-18 board: SparkFun DRC compliance; stricter clearance, bigger vias?
    [pda6502.brd]
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2014-09-21 board, schematics: many adjustments.
    * Different jumper devices.
    * Adafruit TFT board outline.
    * Moved VIA port headers upwards.
    * Overhauled top-right power supply layout.
    * Compacted vias under ROM, route power through freed space.
    * etc...
    [pda6502.brd, pda6502.sch]
2014-09-23 board: many layout / routing adjustments.
    In particular, expansion port has been shifted down closer to edge.
    [pda6502.brd]
2014-09-23 board: shifted 74HC chips down for clearance.
    [pda6502.brd]
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

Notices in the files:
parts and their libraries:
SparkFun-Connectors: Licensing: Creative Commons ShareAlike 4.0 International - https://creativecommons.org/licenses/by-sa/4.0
